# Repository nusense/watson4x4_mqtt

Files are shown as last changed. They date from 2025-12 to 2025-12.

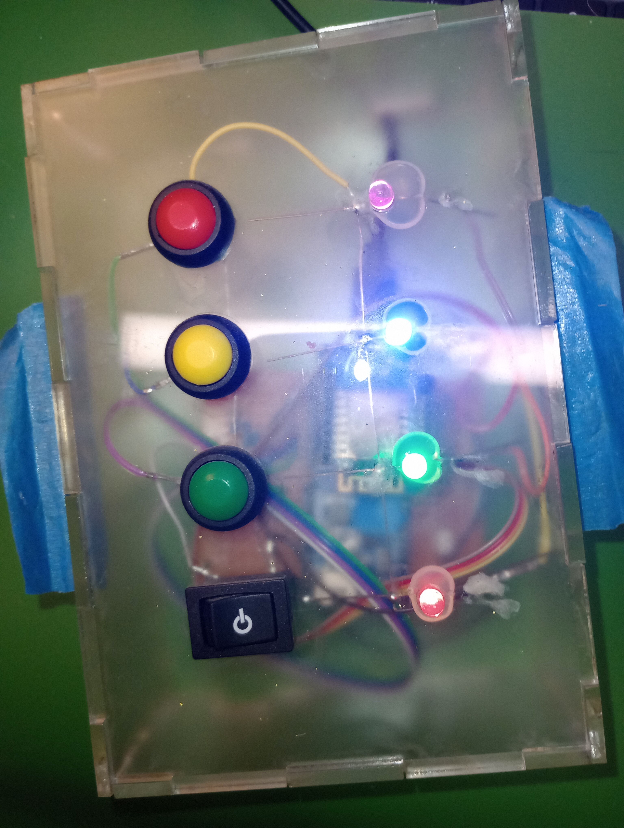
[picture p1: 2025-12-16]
images/box_front_assembled.jpg

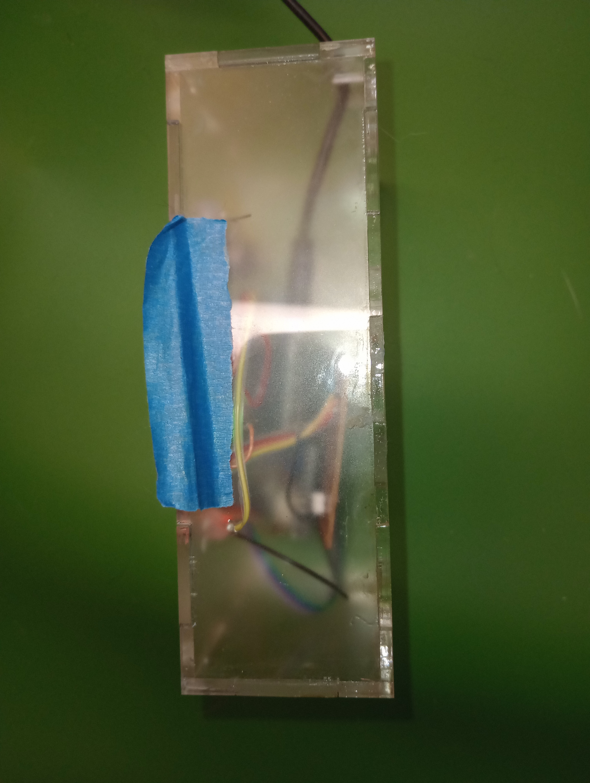
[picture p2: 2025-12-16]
images/box side.jpg

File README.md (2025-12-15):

# watson4x4_mqtt

Watson box project

This project name derives from the story of Alexander Graham Bell's first words over his new telepone (March 10, 1876) which were "Mr. Watson, come here -- I want to see you"

This project was realized, during the early COVID shutdown,  as a pair of boxes each with 4 LEDs and 4 buttons.  Pushing a button toggles the state of the corresponding LED on both boxes.  The purpose is to signal to the person with the other box that attention is needed (in case they are out of hearing range or have their headphones on).

---

### state machine
| init  | | action | | yields | mqtt state |
| ----- | :---:  | --- | :---:  | --- | --- |
| off | &rarr; | push | &rarr; | on (steady) | '1' |
| off | &rarr; | double | &rarr; | slow blink  | 'S' |
| off | &rarr; | triple | &rarr; | fast blink  | 'F' |
| off | &rarr; | long | &rarr; | breathe | 'B' |
| ! off | &rarr; | any push | &rarr; | off | '0' |

Other possible state for LED position is 'X' = super fast blink; this is not settable by button pushes, but only by direct MQTT messaging.

### MQTT topics
State is kept via MQTT communication and retained messages

| topic | box read/write | value |
| --- | --- | ----- |
| rhatcher/watson/state | RW | [LED1][LED2][LED3][LED4] |
| rhatcher/watson/Watson-MAC4 |  W | "client connected" or "client disconnected" |
| rhatcher/watson/Watson-MAC4/brightness | R | 4 # values between 2 - 255 |

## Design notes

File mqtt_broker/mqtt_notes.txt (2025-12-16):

In this case both watson boxes are running on the same network
as is a beaglebone microcomputer (as beaglebone0.local)

The beaglebone has the "mosquitto" MQTT broker installed
(via apt-get install mosquitto, probably also mosquitto-clients)
and uses systemctl to control it

### sudo su to be root

use
   systemctl enable mosquitto
to get it to start on reboot
   systemctl start mosquitto
to start the service immediately

root@beaglebone0:/home/debian# systemctl status mosquitto
● mosquitto.service - LSB: mosquitto MQTT v3.1 message broker
   Loaded: loaded (/etc/init.d/mosquitto; generated; vendor preset: enabled)
   Active: active (running) since Wed 2025-11-26 09:59:52 CST; 2 weeks 5 days ago
     Docs: man:systemd-sysv-generator(8)
   CGroup: /system.slice/mosquitto.service
           └─1031 /usr/sbin/mosquitto -c /etc/mosquitto/mosquitto.conf

root@beaglebone0:/home/debian# cat /etc/mosquitto/mosquitto.conf
-------
# Place your local configuration in /etc/mosquitto/conf.d/
#
# A full description of the configuration file is at
# /usr/share/doc/mosquitto/examples/mosquitto.conf.example
pid_file /var/run/mosquitto.pid
persistence true
persistence_location /var/lib/mosquitto/
log_dest file /var/log/mosquitto/mosquitto.log
include_dir /etc/mosquitto/conf.d
-------

root@beaglebone0:/home/debian# cat /etc/mosquitto/conf.d/default.conf
-------
allow_anonymous false
password_file /etc/mosquitto/passwd
listener 1883
-------

managing passwords
  mosquitto_passwd -c /etc/mosquitto/passwd <username>  # create/overwrite -c, prompts for password
  mosquitto_passwd -b /etc/mosquitto/passwd <myuser2> <mysecretpassword> # add another user -b
currently have users rhatcher and foxbuild (fox.build makerspace)

monitor a topic hierachy (# wildcard)
  mosquitto_sub -h localhost -v -t "rhatcher/watson/#" -u rhatcher -P <password>

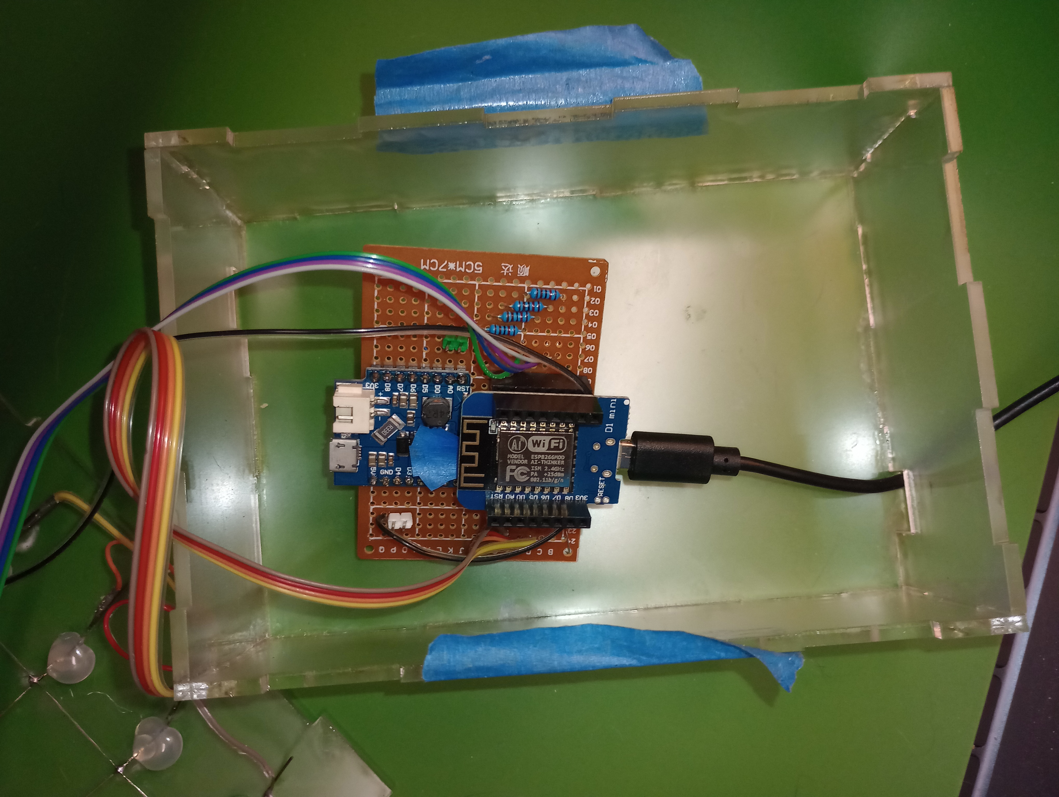
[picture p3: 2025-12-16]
images/wemo_inside_box.jpg

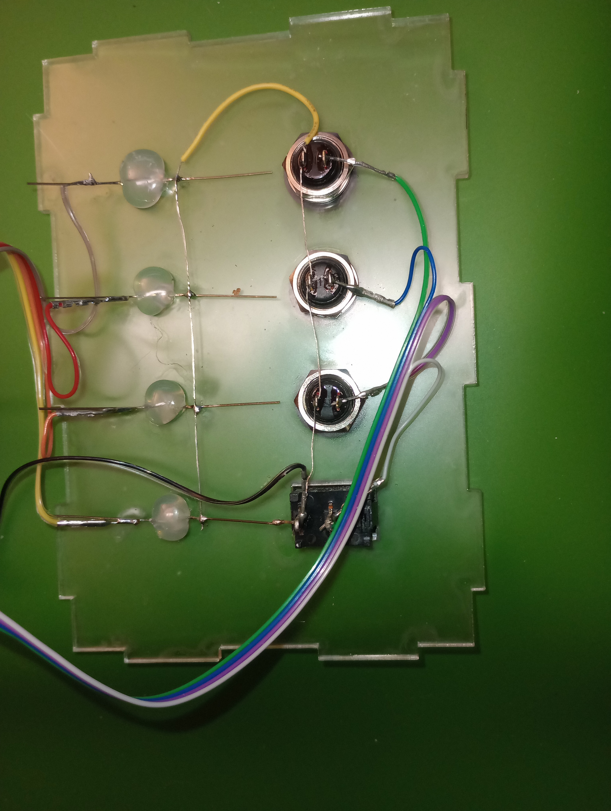
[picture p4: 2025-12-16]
images/backside_box_front.jpg

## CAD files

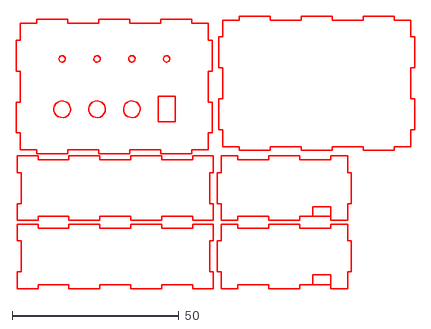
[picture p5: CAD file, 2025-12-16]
box/watson_box_cableholes2.dxf
119.5 x 81.6

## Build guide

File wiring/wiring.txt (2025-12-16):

WEMO D1 mini microcontroller
4 different colored LEDs
4 momentary switches
8 120 Ohm resistors

LED long lead   = anode
LED short lead = cathode

cathode of all LEDs          -> ground
one terminal of all switches -> ground

LED1 anode -> resistor -> WEMO D0
LED2 anode -> resistor -> WEMO D5
LED3 anode -> resistor -> WEMO D6
LED4 anode -> resistor -> WEMO D7

SWTCH1 -> WEMO D1 -> resistor -> WEMO 3.3V
SWTCH2 -> WEMO D2 -> resistor -> WEMO 3.3V
SWTCH3 -> WEMO D3 -> resistor -> WEMO 3.3V
SWTCH4 -> WEMO D4 -> resistor -> WEMO 3.3V

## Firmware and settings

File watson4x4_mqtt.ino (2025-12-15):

                           /************************************************************************************
 * Watson box 
 * Purpose:  a pair of boxes each with 4 LEDs and 4 buttons.  Pushing a button toggles
 *    the state of the corresponding LED on both boxes.  The purpose is to signal to
 *    the person with the other box that attention is needed (in case they are out of
 *    hearing range or have their headphones on).
 *    
 * // state machine
 * //  off   --> push     --> on (steady)  '1'
 * //        --> double   --> slow blink   'S'
 * //        --> triple   --> fast blink   'F'
 * //        --> long     --> breathe      'B'
 * //  ! off --> any push --> off          '0'
 * //    (other possible 'X' super fast blink, but not settable by button)
 *
 * State is kept via MQTT communication and retained messages
 *     rhatcher/watson/state                  RW  'XXXX"
 *     rhatcher/watson/Watson-MAC4            -W  "client connected" or "client disconnected"
 *     rhatcher/watson/Watson-MAC4/brightness R-  <b1> <b2> <b3> <b4>   # values between 2 - 255
 *
 */

#include <ESP8266WiFi.h>
#include <ESP8266mDNS.h>
#include <ArduinoOTA.h>
#include <PubSubClient.h>

#include <jled.h>
#include <DebounceEvent.h>

// version 2.5.3 of esp8266 doesn't define DX pins
#define D0 16
#define D1  5
#define D2  4
#define D3  0
#define D5 14
#define D6 12
#define D7 13
#define D8 15

// hide these
#include "secrets.h"

WiFiClient*   espWifiClient = 0;
PubSubClient* mqttClient    = 0;
byte macAddr[6] = { 0 };
String clientID = "x";

const unsigned int NLED = 4;
int   buttonpins[NLED]       = {  D1,  D2,  D3,  D4 };
int   ledpins[NLED]          = {  D0,  D5,  D6,  D7 };
JLed* leds[NLED]             = {   0,   0,   0,   0 };
DebounceEvent* buttons[NLED] = {   0,   0,   0,   0 };
const int brightMin          =   2;
const int brightMax          = 255;
int   brightness[NLED]       = { 255, 255, 255, 255 };
// need a trailing null char to print this as a string
char  states[NLED+1]           = { 'X', 'X', 'X', 'X', '\0' };

String willTopic    = "x";
String brightTopic  = "x";
String batteryTopic = "x";
String resetTopic   = "x";

// allowed states  X=unknown, 0=off, 1=on, F=fast blink, S=slow b|ink, B=breathe

#define TimeLapse(t1)  (long)((unsigned long)millis()-(unsigned long)t1)
unsigned long startTime = millis();

 // 5min * 60 sec/min * 1000 milli/sec
 #define FIVEMINUTES ( 5 * 60 * 1000 ) 
 
unsigned long t_heartbeat = millis(); // presume we've had an initial heartbeat
unsigned long t_batcheck  = millis() - FIVEMINUTES; // time to check the battery on A0

const char* eventtextp[] = { "EVENT_NONE", "EVENT_CHANGED", "EVENT_PRESSED ", "EVENT_RELEASED" };

void setLedState(int indx, char state) {
  JLed& thisled  = (*leds[indx]);
  char& ledstate = states[indx];
  ledstate = state;

  auto bvalue = brightness[indx];
  switch (ledstate) {
    case '0': 
      thisled.Off().Update();
      break;
    case '1':
      thisled.Set(bvalue).Update();
      break;
    case 'S':
      thisled.Blink(500,500).Forever().DelayAfter(0).MaxBrightness(bvalue).Update();
      break;
    case 'F':
      thisled.Blink(100,100).Forever().DelayAfter(0).MaxBrightness(bvalue).Update();
      break;
    case 'B':
      thisled.Breathe(1500).Forever().DelayAfter(50).MaxBrightness(bvalue).Update();
      break;
    default:
      thisled.Blink(50,50).Forever().DelayAfter(0).MaxBrightness(bvalue).Update();
      ledstate = 'X';
      break;
  }
}

void setBrightnessFromPayload(byte* payload,int len) {
  // be wary of whitespace padding when we tokenize
  // incoming payload may not be null \0 terminated
  String input;
  for (int j=0; j<len; ++j) input += (char)payload[j];
  // trim leading whitespace
  //
  //while (input[0] == ' ' || input[0] == '\t' || input[0] == '\n') {
  //  input.erase(0,1);
  //}
  input.trim();
  input.replace("\t"," ");
  input.replace("\n"," ");
  // reduce all the spaces to singles
  while (input.indexOf("  ") != -1) input.replace("  "," ");
  
  Serial.print("setBrightness \""); Serial.print(input.c_str()); Serial.println("\"    ");

  int indx = 0;  // led index
  int k = 0; // position in "input"
  bool lastOne = false;
  while ( k < len && ! lastOne ) {
    int kWhite = input.indexOf(" ",k);
    if (kWhite < 0 ) lastOne = true;
    Serial.print(" k "); Serial.print(k); Serial.print(" len "); Serial.print(len);
    Serial.print(" kWhite "); Serial.println(kWhite);
    String s = input.substring(k,kWhite);
    int value = s.toInt();
    if (value < brightMin) value = brightMin;
    if (value > brightMax) value = brightMax;
 
    Serial.print(" set led "); Serial.print(indx); Serial.print(" to "); Serial.println(value);
    brightness[indx] = value;
    ++indx;
    if (indx >= NLED ) break; // don't set what we ain't got
    if (kWhite > 0) k = kWhite+1;
  }
  // refresh state just to get updates
  for (int i=0; i<NLED; ++i) {
    // same state, but trigger brightness change
    setLedState(i,states[i]);
  }

}

// mqttCallback the MQTT callback for received messages
void mqttCallback(char* topic, byte* payload, unsigned len) {
  Serial.print("Message arrived [");
  Serial.print(topic);
  Serial.print("] ");
  // assume payloads are chars for this application, but don't count on trailing \0 null
  for (int i=0; i<len; ++i) Serial.print((char)payload[i]);
  Serial.println();

  if ( strcmp(topic,"rhatcher/heartbeat") == 0 ) {
    t_heartbeat = millis();
    // also remind the world we're alive
    mqttClient->publish(willTopic.c_str(),"currently connected"); 
  }

  if ( strcmp(topic,"rhatcher/watson/state") == 0 ) {
    for (int i=0; i<min(len,NLED); ++i) {
      // incoming new state
      setLedState(i,(char)payload[i]);
    }
  }

  if ( strcmp(topic,brightTopic.c_str()) == 0 ) {
    setBrightnessFromPayload(payload,len);
  }
  
}

void mqttReconnect() { // loop until we're connected
  while ( ! mqttClient->connected() ) {
    delay(200);
    Serial.print("Attempting MQTT connection ...");
    // clientID, username, password, willTopic, willQoS, Retain, willMessage);
    willTopic = "rhatcher/watson/" + clientID;
    char* willMessage = "client disconnected";
    brightTopic  = willTopic + "/brightness";
    batteryTopic = willTopic + "/battery";
    resetTopic   = willTopic + "/reset";
    if ( mqttClient->connect(clientID.c_str(), mqtt_user, mqtt_pass, willTopic.c_str(), 2, true, willMessage) ) {
      // connected let the world know
      Serial.println("connected to MQTT");
      delay(500);  // publishing the override to the will too soon seems to get lost sometimes
      mqttClient->publish(willTopic.c_str(),"currently connected");
      mqttClient->subscribe("rhatcher/watson/state");
      mqttClient->subscribe("rhatcher/heartbeat");
      mqttClient->subscribe(brightTopic.c_str());
    } else {
      Serial.print("failed, rc="); Serial.print(mqttClient->state());
      Serial.println(" try again in 2 seconds");
      delay(2000);
    }
  }
}



int buttonGPIO2index(uint8_t pin) {
  for (int i=0; i<NLED; ++i) {
    if ( buttonpins[i] == pin ) return i;
  }
  return -1;
}

char* GPIO2DPin(uint8_t pin) {
  switch (pin) {
    case D0: return "D0";  break;
    case D1: return "D1";  break;
    case D2: return "D2";  break;
    case D3: return "D3";  break;
    case D4: return "D4";  break;
    case D5: return "D5";  break;
    case D6: return "D6";  break;
    case D7: return "D7";  break;
    case D8: return "D8";  break;
    default:  return "??";
  }
}

void buttonCallback(uint8_t pin, uint8_t event, uint8_t count, uint16_t len) {

    if ( event != EVENT_RELEASED ) {
    // not interested so much in these
    Serial.println();
    return;
  }
  
  Serial.print("Pin: ");     Serial.print(pin);
  Serial.print(" ");         Serial.print(GPIO2DPin(pin)); 
  int indx = buttonGPIO2index(pin);
  if (indx < 0 || indx > NLED ) {
    Serial.print(" bad index: ");  Serial.print(indx);
    Serial.println();
    return;
  }
  char& ledstate = states[indx];
  Serial.print(" Indx: ");   Serial.print(indx);  Serial.print(" '"); Serial.print(ledstate); Serial.print("'");
  Serial.print(" Event: ");  Serial.print(event); Serial.print(" "); Serial.print(eventtextp[event]);
  Serial.print(" Count: ");  Serial.print(count);
  Serial.print(" Length: "); Serial.print(len);

  // state machine
  //  off   --> push   --> on (steady)
  //        --> double --> slow blink
  //        --> triple --> fast blink
  //        --> long   --> breathe

  //  ! off --> push --> off

  // for sciplus buttons normal length ~ 175-200,  long push > 500
  // for         rocker                  200-350             > 500     

//  JLed& thisled  = (*leds[indx]);

  if (ledstate == '0') {
    if (len > 500 ) {
      setLedState(indx,'B');
    } else {
      switch (count) {
        case 1: setLedState(indx,'1'); break;
        case 2: setLedState(indx,'S'); break;
        case 3: setLedState(indx,'F'); break;
        default:
          setLedState(indx,'X'); break;
       }
    }
  } else {
    setLedState(indx,'0');
  }

  Serial.print(" ["); Serial.print(states); Serial.print("]");
  Serial.println();

  if (mqttClient ) {
    Serial.println("publish states");
    // publish a _retained_ message
    // this allow a box coming online to pick up the current/last state
    // if using char* the method takes 3 args (no "length") despite unclear documentation
    mqttClient->publish("rhatcher/watson/state",states,true);
  }

}

char convertToHexDigit(byte b) {
  if ( b  < 10 ) return b + '0';
  return b - 10 + 'A';
}

String convertMACLower4toStr() {
  String s;
  
  Serial.print("MAC: ");
  Serial.print(macAddr[0],HEX);
  Serial.print(":");
  Serial.print(macAddr[1],HEX);
  Serial.print(":");
  Serial.print(macAddr[2],HEX);
  Serial.print(":");
  Serial.print(macAddr[3],HEX);
  Serial.print(":");
  Serial.print(macAddr[4],HEX);
  Serial.print(":");
  Serial.println(macAddr[5],HEX);
  
  Serial.print(" macAddr[4] "); Serial.print(macAddr[4]);
  Serial.print(" macAddr[5] "); Serial.print(macAddr[5]);
  Serial.println();
  
  byte nibbles[4] = { 0, 0, 0, 0 };
  nibbles[0] = ( macAddr[4] >> 4 ) & 0xF;
  nibbles[1] = ( macAddr[4]      ) & 0xF ;
  nibbles[2] = ( macAddr[5] >> 4 ) & 0xF ;
  nibbles[3] = ( macAddr[5]      ) & 0xF ;
  
  for (int j=0; j<4; ++j ) {
    Serial.print("nibble "); Serial.print(j); Serial.print(" value "); Serial.println(nibbles[j]);
    char c = convertToHexDigit(nibbles[j]);
    s += c;
  }
  
//  for (int i=0; i<6; ++i) {
//    char c = (char)macAddr[i]; // already HEX?  convertToHexDigit(macAddr[i]);
//    s += c;
//  }
  Serial.print("convert MACtoStr ");
  Serial.print(s);
  Serial.println();
  return s;
}

void setup() {
  
  Serial.begin(115200);
  Serial.println(" "); // move beyond upload noise
  Serial.print("setup: ");

  // initialize LEDs and turn them off as the objects are created, record this state
  for (int i=0; i<NLED; ++i) {
    Serial.println();
    Serial.print("i="); Serial.print(i);
    auto ledpin = ledpins[i];
    pinMode(ledpin,OUTPUT);
    Serial.print(" led "); Serial.print(GPIO2DPin(ledpin));
    JLed* ledptr = new JLed(ledpin);
    leds[i] = ledptr;
    states[i] = '0';
    (*ledptr).Off();
    auto bpin = buttonpins[i];
    Serial.print(" button "); Serial.print(GPIO2DPin(bpin));
    // there something special with D8 ... won't flash program with it pulled up, so avoid it
    DebounceEvent* buttonptr = new DebounceEvent(bpin,buttonCallback, BUTTON_PUSHBUTTON | BUTTON_DEFAULT_HIGH );
    buttons[i] = buttonptr;
    Serial.print(" i="); Serial.print(i); 
    Serial.print(" ["); Serial.print(ledpin); Serial.print(","); Serial.print(bpin); Serial.print("] ");
  }  

  int wifiStatus = WL_IDLE_STATUS;
  WiFi.mode(WIFI_STA);
  wifiStatus = WiFi.begin(ssid,password);
  while (WiFi.waitForConnectResult() != WL_CONNECTED) {
    Serial.println("Connection Failed!  Rebooting...");
    delay(5000);
    ///ESP.restart();
    return;
  } 

   WiFi.macAddress(macAddr);
   // hostname defaults to sep8266-[ChipID]

   // create an unique clientID for MQTT
   clientID = "Watson-";
   clientID += convertMACLower4toStr();
   Serial.print("clientID is ");
   Serial.println(clientID);

  // put ArduinoOTA stuff here
  ArduinoOTA.setHostname(clientID.c_str());
  // No authentication by default
  // ArduinoOTA.setPassword((const char*)"1234");
  ArduinoOTA.onStart([]() {
    Serial.println("ArduinoOTA.onStart");
  });
  ArduinoOTA.onEnd([]() {
    Serial.println("\nArduinoOTA.onEnd");
  });
  ArduinoOTA.onProgress([](unsigned int progress, unsigned int total) {
    Serial.printf("ArduinoOTA.onProgress: %u%%\r", (progress / (total / 100)));
  });
  ArduinoOTA.onError([](ota_error_t error) {
    Serial.printf("ArduinoOTA.onError[%u]: ", error);
    if      ( error == OTA_AUTH_ERROR    ) Serial.println("Auth Failed");
    else if ( error == OTA_BEGIN_ERROR   ) Serial.println("Begin Failed");
    else if ( error == OTA_CONNECT_ERROR ) Serial.println("Connect Failed");
    else if ( error == OTA_RECEIVE_ERROR ) Serial.println("Receive Failed");
    else if ( error == OTA_END_ERROR     ) Serial.println("End Failed");
    else { Serial.println("Unknown error"); }
  });
  ArduinoOTA.begin();

  Serial.print("local IP Address: "); Serial.println(WiFi.localIP());

  // MQTT setup
  espWifiClient = new WiFiClient();
  mqttClient    = new PubSubClient(*espWifiClient);
  mqttClient->setServer(mqtt_server, 1883);
  mqttClient->setCallback(mqttCallback);
  
  Serial.println(" ... end setup");
}

void loop() {

  ArduinoOTA.handle();

  if (mqttClient) {
    if (! mqttClient->connected() ) mqttReconnect();
    mqttClient->loop();  // look for messages we subscribed to
  }

  // update buttons, leds
  for (int i=0; i<NLED; ++i) {
    buttons[i]->loop();
    leds[i]->Update();
  }

  if (TimeLapse(t_batcheck) > FIVEMINUTES ) {
    t_batcheck = millis();
    int val = analogRead(A0);
    float f = 3.3 * (float)val/1024.0;
    String msg = "battery at ";
    msg += f;
    msg += " V  (";
    msg += val;
    msg += ")";
    mqttClient->publish(batteryTopic.c_str(),msg.c_str());
  }

  // have we heard a heartbeat lately 
  if (TimeLapse(t_heartbeat) > FIVEMINUTES ) {
    mqttClient->publish(resetTopic.c_str(),"hard reset from lack of heartbeats");   
    Serial.println("force reset due to lack of heartbeats");
    ESP.reset();
  }
  
}
